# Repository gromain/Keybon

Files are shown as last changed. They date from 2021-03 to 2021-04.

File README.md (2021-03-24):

# Keybon - Adaptive Macro Keyboard

Keybon is a macro keyboard with configurable layouts and functions. Integrated into each of its nine tactile buttons is a 0.66” OLED screen. Depending on which app is active on the connected computer, Keybon switches to the suitable key layout thanks to its companion software.

This repository also contains a 12 buttons version called Keybon12. The corresponding files and code were designed by Romain Bazile. It's built upon the work of [CoretechR](https://github.com/CoretechR/Keybon/).

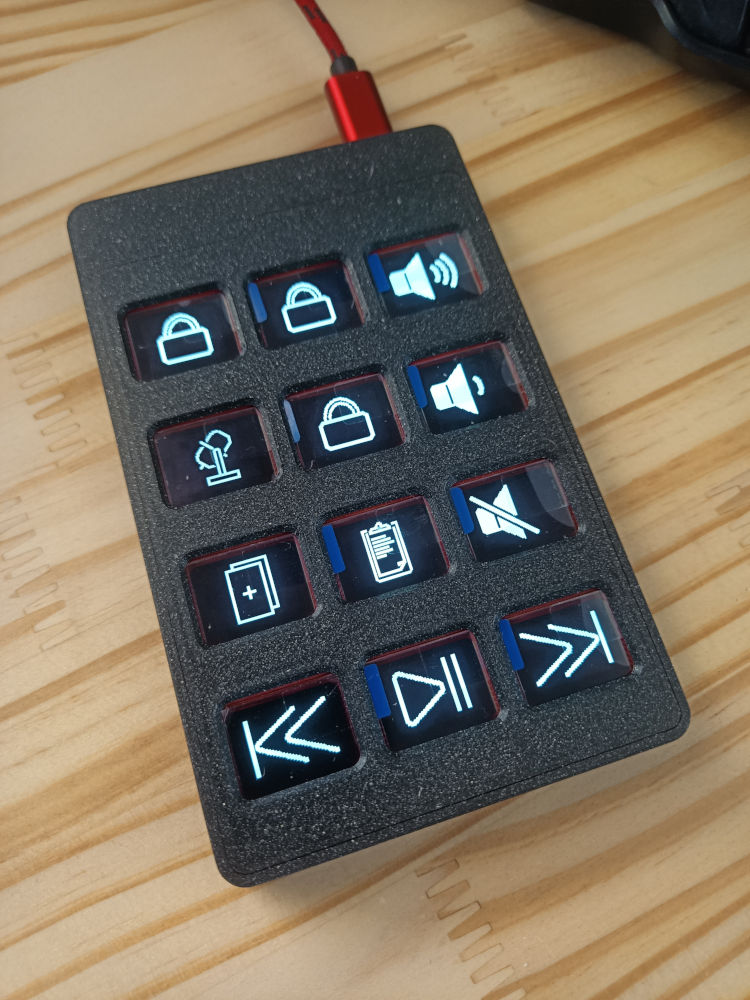
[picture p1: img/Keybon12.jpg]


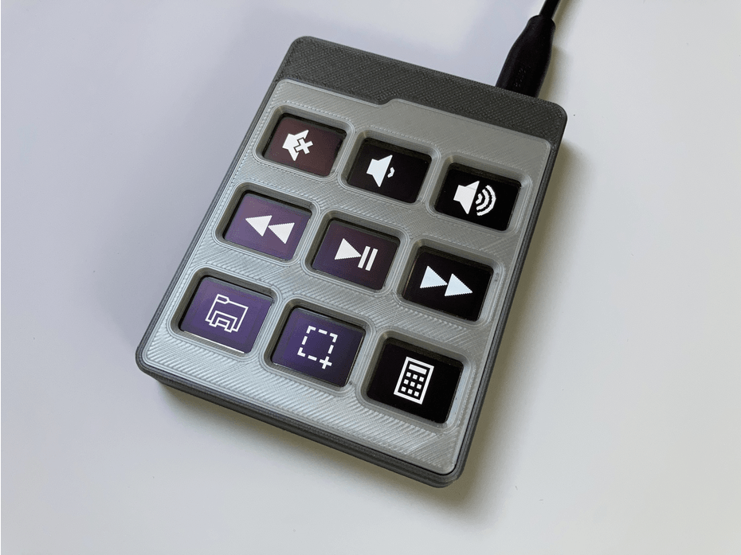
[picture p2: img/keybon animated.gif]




# Instructions

1.  Download the USB bootloader: https://github.com/rogerclarkmelbourne/STM32duino-bootloader

    Connect a USB-to-Serial adapter to the TX/RX pins of your board. Close the BOOT0 jumper before applying power.

    Locate the file to flash, in the folder `bootloader_only_binaries/generic_boot20_pc13.bin`.

    Flash the USB bootloader to the STM32 via the STM32 flasher:  https://www.st.com/en/development-tools/flasher-stm32.html

    You can also use the `stm32loader.py` script provided by `STM32duino-bootloader` team.

    Do not forget to remove the BOOT0 jumper once you're done.

2.  Install the required Arduino libraries listed in the `keybon12.ino` file

    Important: **Adafruit_GFX_Library version 1.7.5** must be installed (dependencies for newer versions are incompatible with the STM32)

    Add these lines to the file `Adafruit_SSD1306.c` (in `Arduino/libraries/Adafruit_SSD1306`)
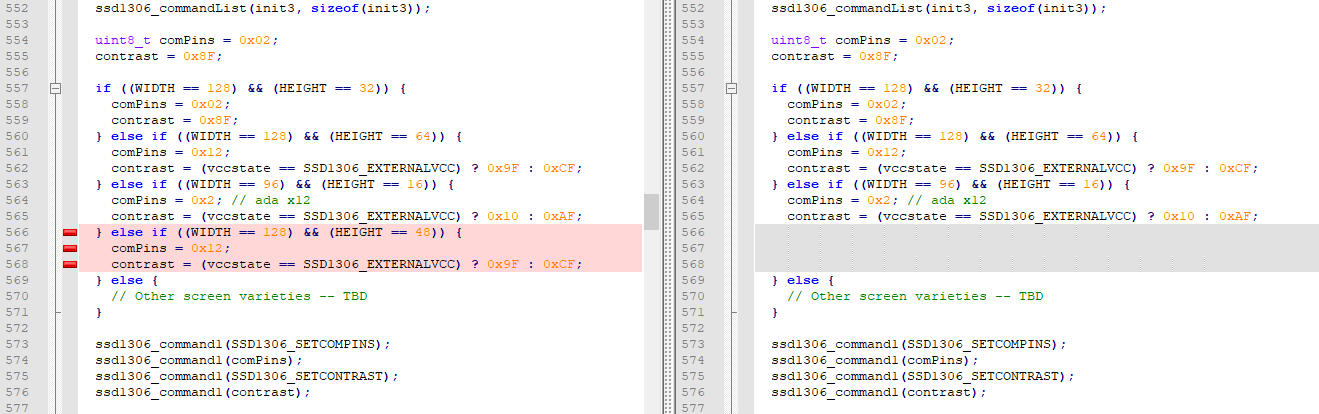
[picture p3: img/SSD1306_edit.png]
    
    ```C++
    } else if ((WIDTH == 128) && (HEIGHT == 48)) {
    comPins = 0x12;
	  contrast = (vccstate == SSD1306_EXTERNALVCC) ? 0x9F : 0xCF;
    ```

    They should be added around line 563, right after this:
    ```C++
    } else if ((WIDTH == 96) && (HEIGHT == 16)) {
    comPins = 0x2; // ada x12
    contrast = (vccstate == SSD1306_EXTERNALVCC) ? 0x10 : 0xAF;
    ```

3.  Install STM32 support for the Arduino IDE: https://github.com/rogerclarkmelbourne/Arduino_STM32

    Install the corresponding drivers: https://github.com/rogerclarkmelbourne/Arduino_STM32/tree/master/drivers

4.  Compile and upload the Arduino sketch:

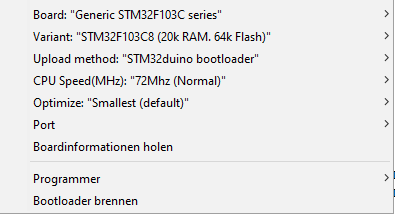
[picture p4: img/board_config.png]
    

    The first time you do this, you will need to short the BOOT1 jumper and then restart your Keybon (either by plugging it in, or by clicking on the reset button).

    If you are using Linux, you may need to add a udev rule to your system (or to use `sudo` with the last command executed by the Arduino IDE).

    If you need to create new icons for your display, you can use the tool at https://javl.github.io/image2cpp/ with png images, in black and white only and a resolution of 64*48 pixels.

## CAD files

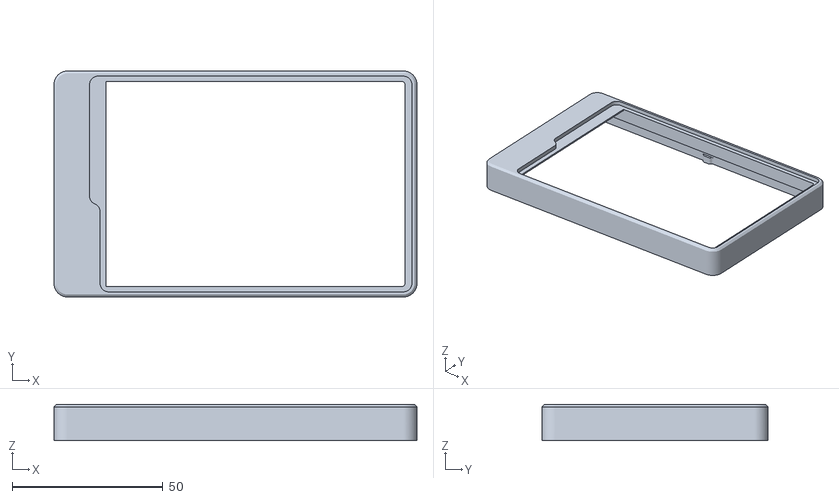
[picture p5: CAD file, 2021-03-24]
CAD Files/Shell Keybon12.stl
120.5 x 75.0 x 12.0

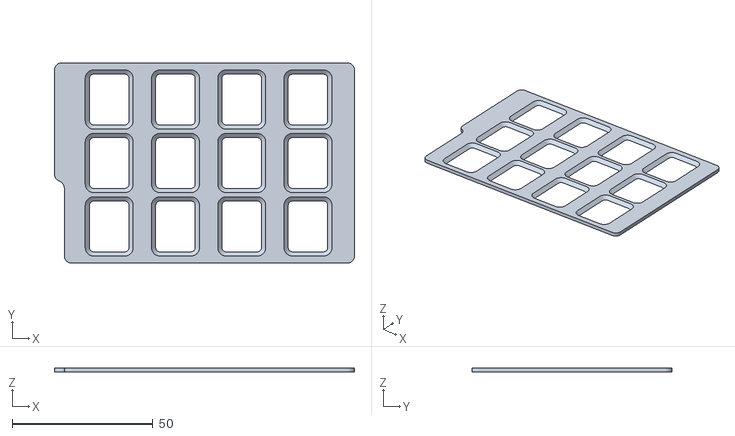
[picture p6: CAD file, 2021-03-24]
CAD Files/Cover Plate Keybon12.stl
106.4 x 71.0 x 1.50

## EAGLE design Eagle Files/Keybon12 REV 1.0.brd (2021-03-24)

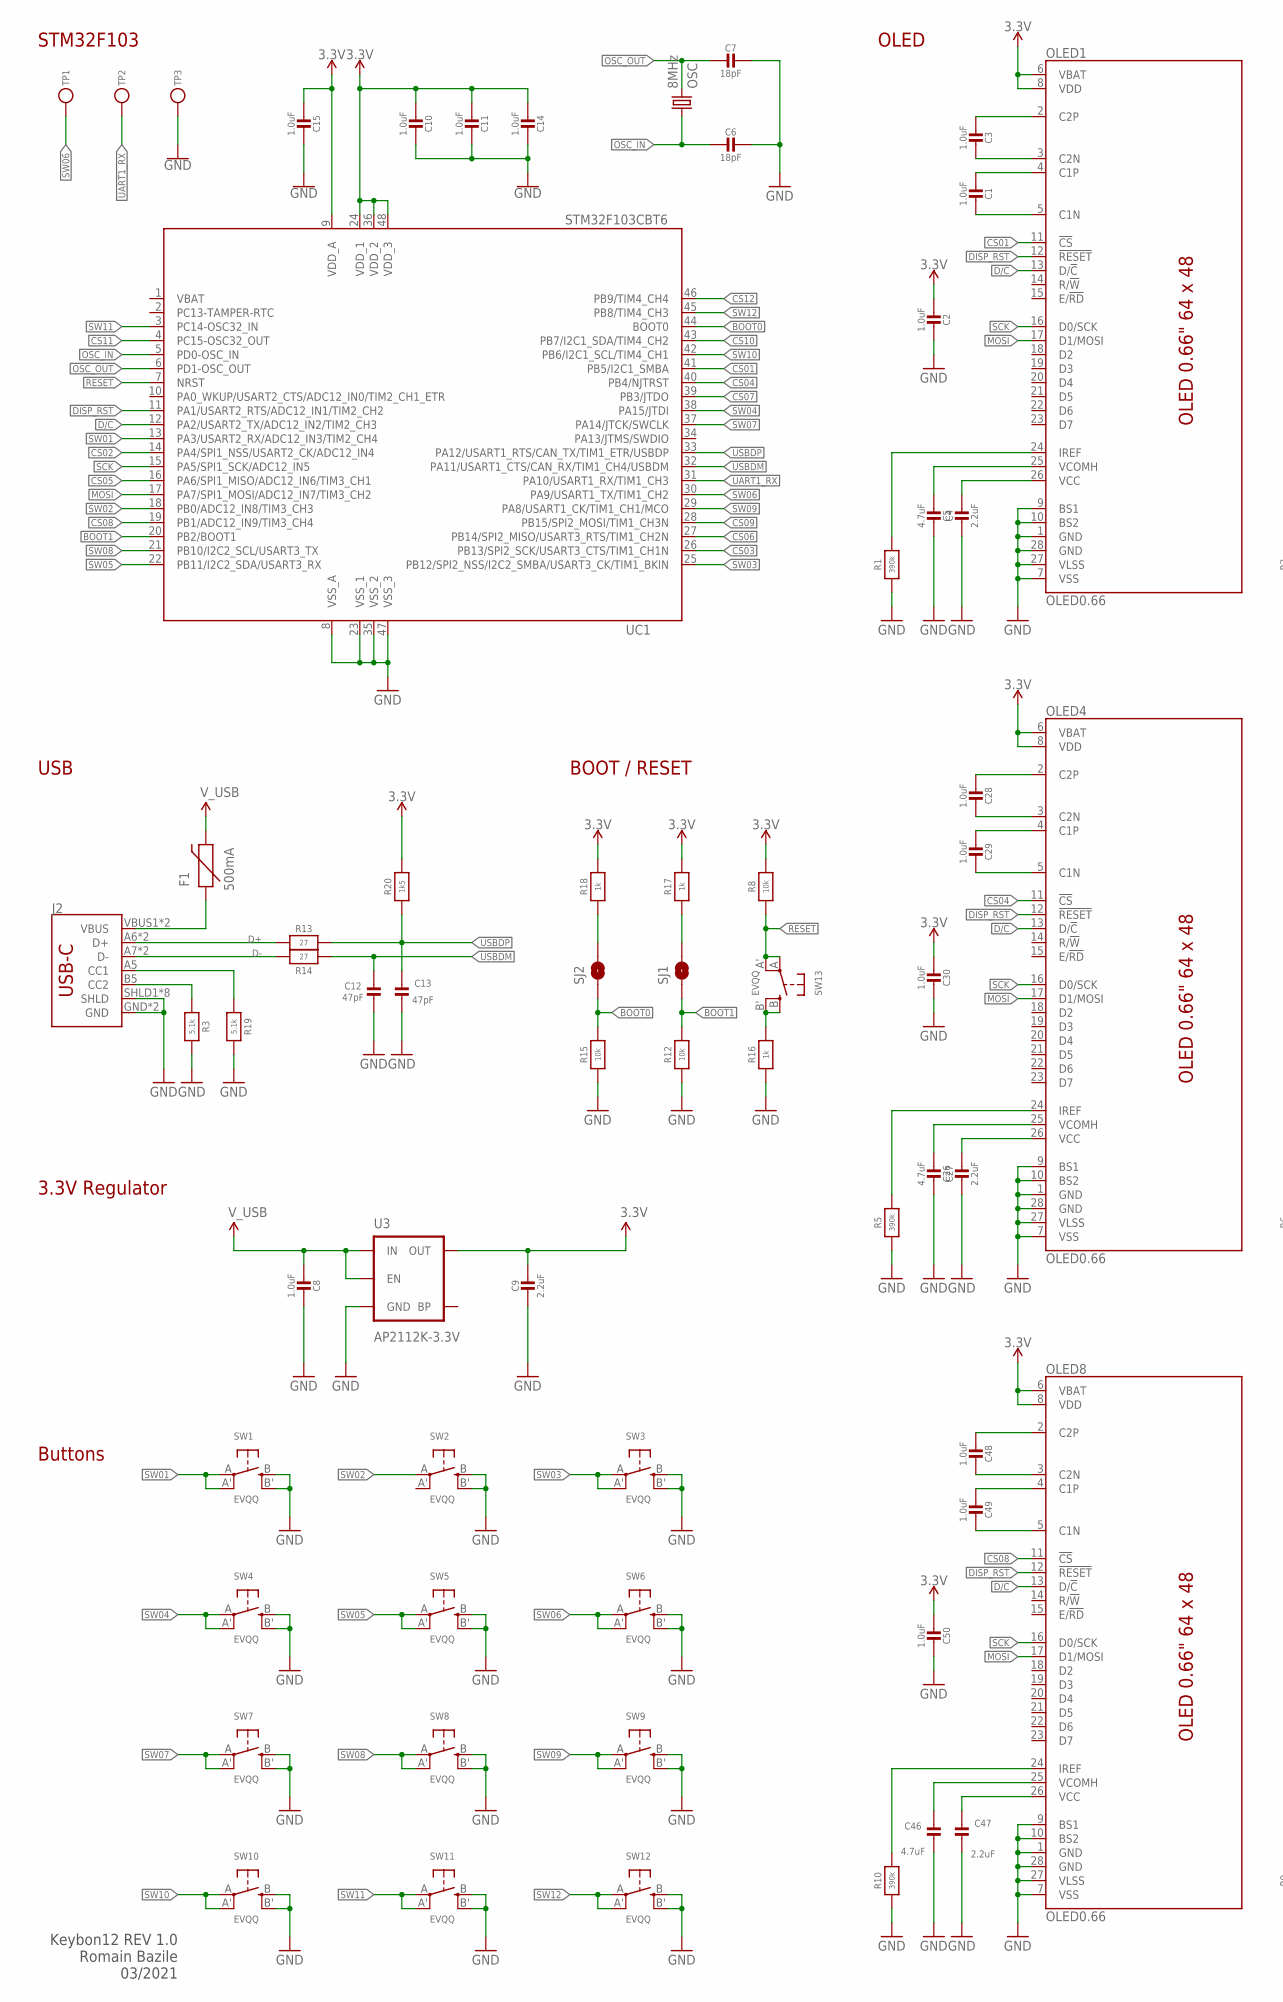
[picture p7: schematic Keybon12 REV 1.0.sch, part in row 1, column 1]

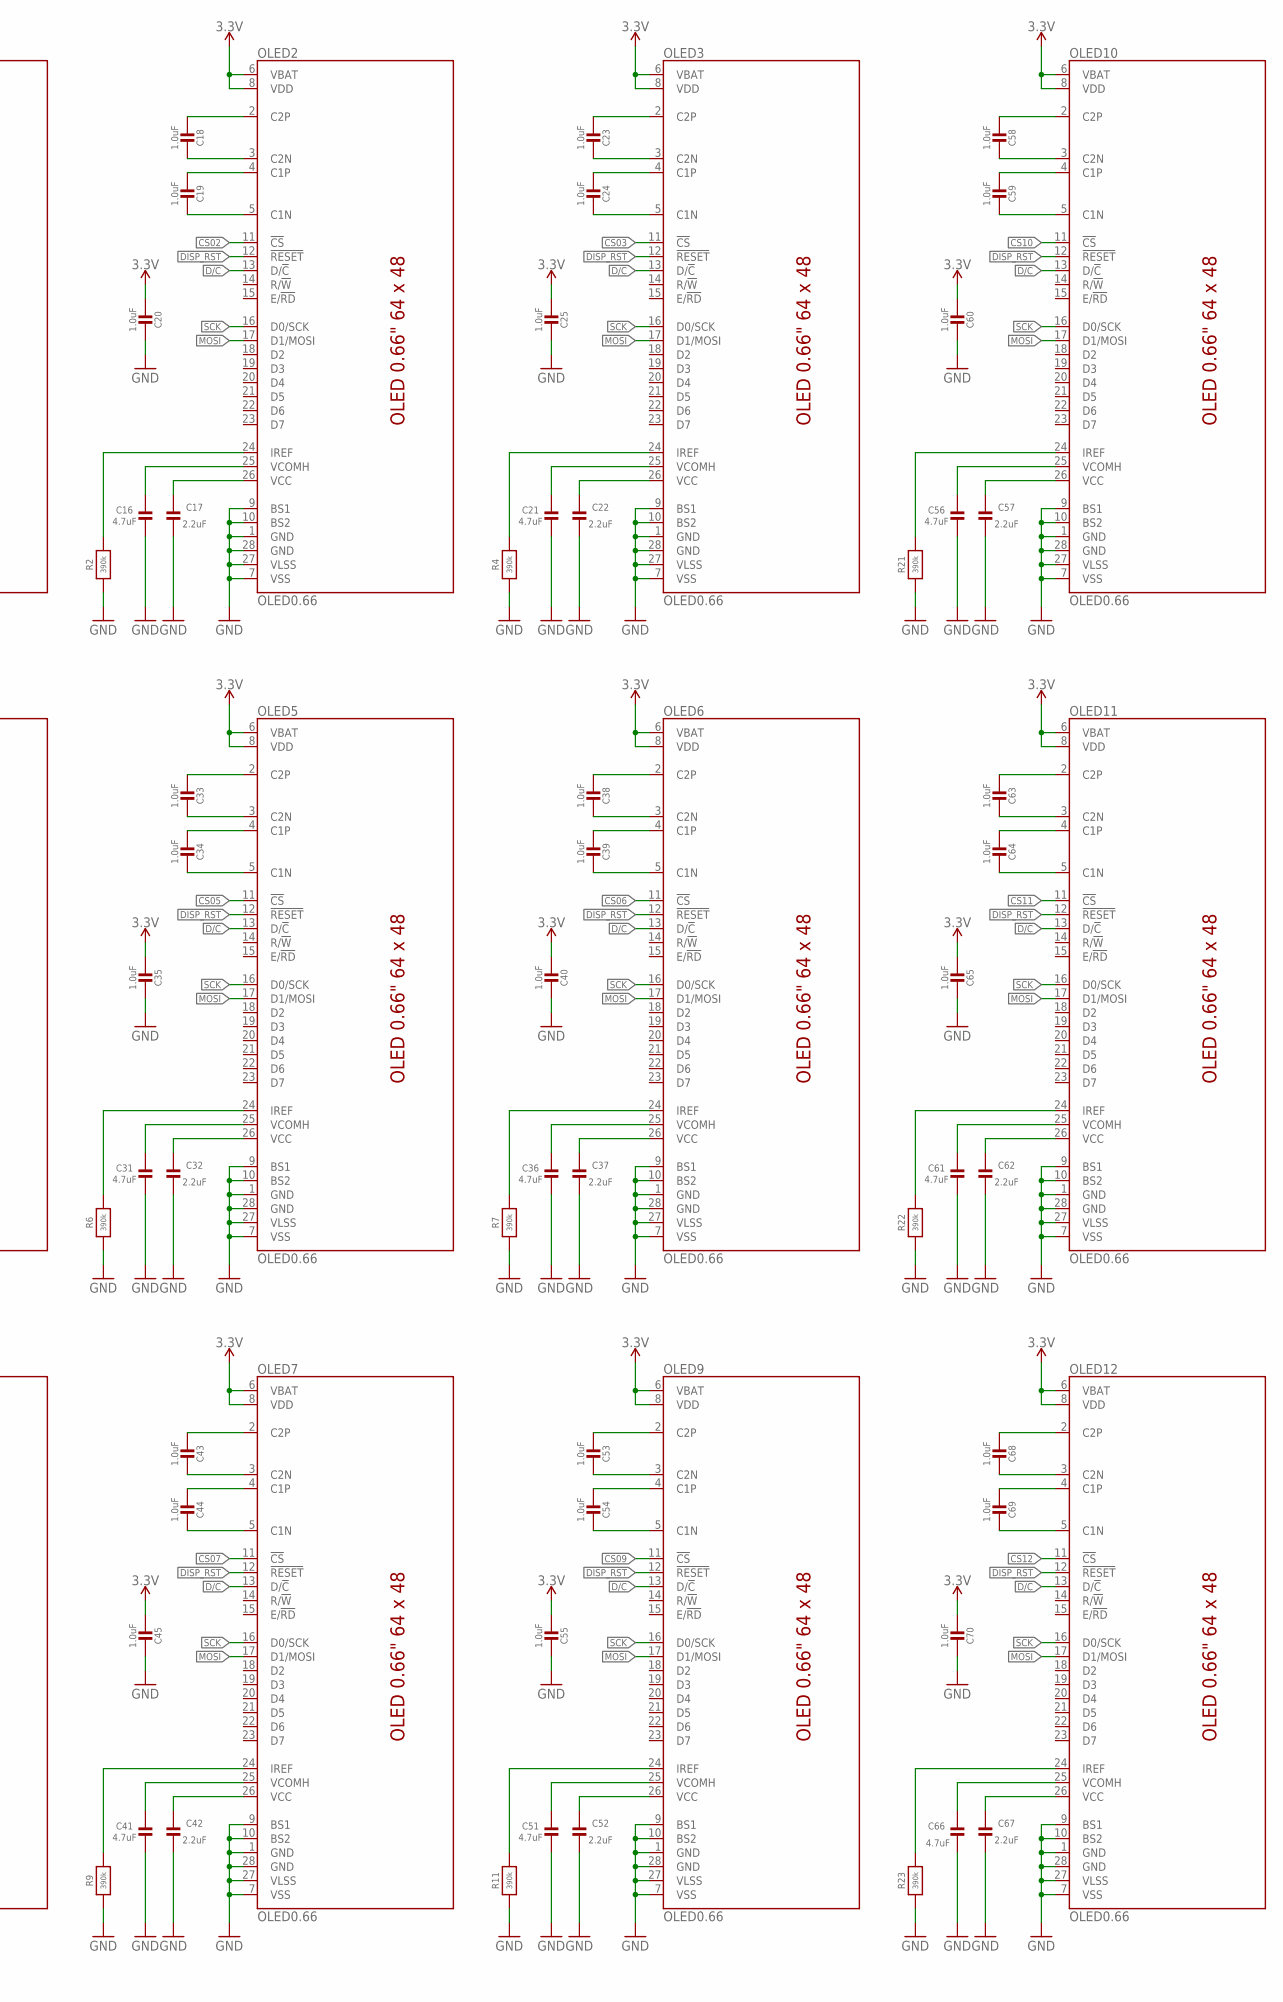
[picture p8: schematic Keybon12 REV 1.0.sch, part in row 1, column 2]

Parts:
C1, C2, C3, C8, C10, C11, C14, C15, C18, C19, C20, C23, C24, C25, C28, C29, C30, C33, C34, C35, C38, C39, C40, C43, C44, C45, C48, C49, C50, C53, C54, C55, C58, C59, C60, C63, C64, C65, C68, C69, C70: 1.0uF; _0805MP
C4, C9, C17, C22, C27, C32, C37, C42, C47, C52, C57, C62, C67: 2.2uF; _0805MP
C5, C16, C21, C26, C31, C36, C41, C46, C51, C56, C61, C66: 4.7uF; _0805MP
C6, C7: 18pF; _0805MP
C12, C13: 47pF; _0805MP
F1: 500mA; PTC-1206
J2: USB_C16PIN; USB-C-16P
OLED1, OLED2, OLED3, OLED4, OLED5, OLED6, OLED7, OLED8, OLED9, OLED10, OLED11, OLED12: OLED0.66; OLED-0.66-64X48
OSC: 8MHz; CRYSTAL-SMD-5X3
R1, R2, R4, R5, R6, R7, R9, R10, R11, R21, R22, R23: 390k; _0805MP
R3, R19: 5.1k; _0805MP
R8, R12, R15: 10k; _0805MP
R13, R14: 27; _0805MP
R16, R17, R18: 1k; _0805MP
R20: 1k5; _0805MP
SJ1, SJ2: JUMPER-PAD-2-NOYES_SILK; PAD-JUMPER-2-NO_YES_SILK
SW1, SW2, SW3, SW4, SW5, SW6, SW7, SW8, SW9, SW10, SW11, SW12, SW13: EVQQ; EVQ-Q2_SMALLER
TP1, TP2, TP3: TESTPOINTPAD2MM; TESTPOINT_PAD_2MM
U3: AP2112K-3.3V; SOT23-5
UC1: STM32F103CBT6; LQFP48

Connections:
3.3V: C2.1, C9.1, C10.1, C11.1, C14.1, C15.1, C20.1, C25.1, C30.1, C35.1, C40.1, C45.1, C50.1, C55.1, C60.1, C65.1, C70.1, OLED1.6 (VBAT), OLED1.8 (VDD), OLED2.6 (VBAT), OLED2.8 (VDD), OLED3.6 (VBAT), OLED3.8 (VDD), OLED4.6 (VBAT), OLED4.8 (VDD), OLED5.6 (VBAT), OLED5.8 (VDD), OLED6.6 (VBAT), OLED6.8 (VDD), OLED7.6 (VBAT), OLED7.8 (VDD), OLED8.6 (VBAT), OLED8.8 (VDD), OLED9.6 (VBAT), OLED9.8 (VDD), OLED10.6 (VBAT), OLED10.8 (VDD), OLED11.6 (VBAT), OLED11.8 (VDD), OLED12.6 (VBAT), OLED12.8 (VDD), R8.2, R17.2, R18.2, R20.2, U3.5 (OUT), UC1.9 (VDD_A), UC1.24 (VDD_1), UC1.36 (VDD_2), UC1.48 (VDD_3)
BOOT0: R15.2, SJ2.1, UC1.44 (BOOT0)
BOOT1: R12.2, SJ1.1, UC1.20 (PB2/BOOT1)
C1N: C1.2, OLED1.5 (C1N)
C1N1: C19.2, OLED2.5 (C1N)
C1N2: C24.2, OLED3.5 (C1N)
C1N3: C29.2, OLED4.5 (C1N)
C1N4: C34.2, OLED5.5 (C1N)
C1N5: C39.2, OLED6.5 (C1N)
C1N6: C44.2, OLED7.5 (C1N)
C1N7: C49.2, OLED8.5 (C1N)
C1N8: C54.2, OLED9.5 (C1N)
C1N9: C59.2, OLED10.5 (C1N)
C1N10: C64.2, OLED11.5 (C1N)
C1N11: C69.2, OLED12.5 (C1N)
C1P: C1.1, OLED1.4 (C1P)
C1P1: C19.1, OLED2.4 (C1P)
C1P2: C24.1, OLED3.4 (C1P)
C1P3: C29.1, OLED4.4 (C1P)
C1P4: C34.1, OLED5.4 (C1P)
C1P5: C39.1, OLED6.4 (C1P)
C1P6: C44.1, OLED7.4 (C1P)
C1P7: C49.1, OLED8.4 (C1P)
C1P8: C54.1, OLED9.4 (C1P)
C1P9: C59.1, OLED10.4 (C1P)
C1P10: C64.1, OLED11.4 (C1P)
C1P11: C69.1, OLED12.4 (C1P)
C2N: C3.2, OLED1.3 (C2N)
C2N1: C18.2, OLED2.3 (C2N)
C2N2: C23.2, OLED3.3 (C2N)
C2N3: C28.2, OLED4.3 (C2N)
C2N4: C33.2, OLED5.3 (C2N)
C2N5: C38.2, OLED6.3 (C2N)
C2N6: C43.2, OLED7.3 (C2N)
C2N7: C48.2, OLED8.3 (C2N)
C2N8: C53.2, OLED9.3 (C2N)
C2N9: C58.2, OLED10.3 (C2N)
C2N10: C63.2, OLED11.3 (C2N)
C2N11: C68.2, OLED12.3 (C2N)
C2P: C3.1, OLED1.2 (C2P)
C2P1: C18.1, OLED2.2 (C2P)
C2P2: C23.1, OLED3.2 (C2P)
C2P3: C28.1, OLED4.2 (C2P)
C2P4: C33.1, OLED5.2 (C2P)
C2P5: C38.1, OLED6.2 (C2P)
C2P6: C43.1, OLED7.2 (C2P)
C2P7: C48.1, OLED8.2 (C2P)
C2P8: C53.1, OLED9.2 (C2P)
C2P9: C58.1, OLED10.2 (C2P)
C2P10: C63.1, OLED11.2 (C2P)
C2P11: C68.1, OLED12.2 (C2P)
CS01: OLED1.11 (!CS!), UC1.41 (PB5/I2C1_SMBA)
CS02: OLED2.11 (!CS!), UC1.14 (PA4/SPI1_NSS/USART2_CK/ADC12_IN4)
CS03: OLED3.11 (!CS!), UC1.26 (PB13/SPI2_SCK/USART3_CTS/TIM1_CH1N)
CS04: OLED4.11 (!CS!), UC1.40 (PB4/NJTRST)
CS05: OLED5.11 (!CS!), UC1.16 (PA6/SPI1_MISO/ADC12_IN6/TIM3_CH1)
CS06: OLED6.11 (!CS!), UC1.27 (PB14/SPI2_MISO/USART3_RTS/TIM1_CH2N)
CS07: OLED7.11 (!CS!), UC1.39 (PB3/JTDO)
CS08: OLED8.11 (!CS!), UC1.19 (PB1/ADC12_IN9/TIM3_CH4)
CS09: OLED9.11 (!CS!), UC1.28 (PB15/SPI2_MOSI/TIM1_CH3N)
CS10: OLED10.11 (!CS!), UC1.43 (PB7/I2C1_SDA/TIM4_CH2)
CS11: OLED11.11 (!CS!), UC1.4 (PC15-OSC32_OUT)
CS12: OLED12.11 (!CS!), UC1.46 (PB9/TIM4_CH4)
D+: J2.A6 (D+), J2.B6 (D+), R13.1
D-: J2.A7 (D-), J2.B7 (D-), R14.1
D/C: OLED1.13 (D/!C!), OLED2.13 (D/!C!), OLED3.13 (D/!C!), OLED4.13 (D/!C!), OLED5.13 (D/!C!), OLED6.13 (D/!C!), OLED7.13 (D/!C!), OLED8.13 (D/!C!), OLED9.13 (D/!C!), OLED10.13 (D/!C!), OLED11.13 (D/!C!), OLED12.13 (D/!C!), UC1.12 (PA2/USART2_TX/ADC12_IN2/TIM2_CH3)
DISP_RST: OLED1.12 (!RESET!), OLED2.12 (!RESET!), OLED3.12 (!RESET!), OLED4.12 (!RESET!), OLED5.12 (!RESET!), OLED6.12 (!RESET!), OLED7.12 (!RESET!), OLED8.12 (!RESET!), OLED9.12 (!RESET!), OLED10.12 (!RESET!), OLED11.12 (!RESET!), OLED12.12 (!RESET!), UC1.11 (PA1/USART2_RTS/ADC12_IN1/TIM2_CH2)
GND: C2.2, C4.2, C5.2, C6.1, C7.1, C8.2, C9.2, C10.2, C11.2, C12.2, C13.2, C14.2, C15.2, C16.2, C17.2, C20.2, C21.2, C22.2, C25.2, C26.2, C27.2, C30.2, C31.2, C32.2, C35.2, C36.2, C37.2, C40.2, C41.2, C42.2, C45.2, C46.2, C47.2, C50.2, C51.2, C52.2, C55.2, C56.2, C57.2, C60.2, C61.2, C62.2, C65.2, C66.2, C67.2, C70.2, J2.GND, J2.GND2 (GND), J2.SHLD1 (SHLD), J2.SHLD2 (SHLD), J2.SHLD3 (SHLD), J2.SHLD4 (SHLD), J2.SHLD5 (SHLD), J2.SHLD6 (SHLD), J2.SHLD7 (SHLD), J2.SHLD8 (SHLD), OLED1.1 (GND), OLED1.7 (VSS), OLED1.9 (BS1), OLED1.10 (BS2), OLED1.27 (VLSS), OLED1.28 (GND), OLED2.1 (GND), OLED2.7 (VSS), OLED2.9 (BS1), OLED2.10 (BS2), OLED2.27 (VLSS), OLED2.28 (GND), OLED3.1 (GND), OLED3.7 (VSS), OLED3.9 (BS1), OLED3.10 (BS2), OLED3.27 (VLSS), OLED3.28 (GND), OLED4.1 (GND), OLED4.7 (VSS), OLED4.9 (BS1), OLED4.10 (BS2), OLED4.27 (VLSS), OLED4.28 (GND), OLED5.1 (GND), OLED5.7 (VSS), OLED5.9 (BS1), OLED5.10 (BS2), OLED5.27 (VLSS), OLED5.28 (GND), OLED6.1 (GND), OLED6.7 (VSS), OLED6.9 (BS1), OLED6.10 (BS2), OLED6.27 (VLSS), OLED6.28 (GND), OLED7.1 (GND), OLED7.7 (VSS), OLED7.9 (BS1), OLED7.10 (BS2), OLED7.27 (VLSS), OLED7.28 (GND), OLED8.1 (GND), OLED8.7 (VSS), OLED8.9 (BS1), OLED8.10 (BS2), OLED8.27 (VLSS), OLED8.28 (GND), OLED9.1 (GND), OLED9.7 (VSS), OLED9.9 (BS1), OLED9.10 (BS2), OLED9.27 (VLSS), OLED9.28 (GND), OLED10.1 (GND), OLED10.7 (VSS), OLED10.9 (BS1), OLED10.10 (BS2), OLED10.27 (VLSS), OLED10.28 (GND), OLED11.1 (GND), OLED11.7 (VSS), OLED11.9 (BS1), OLED11.10 (BS2), OLED11.27 (VLSS), OLED11.28 (GND), OLED12.1 (GND), OLED12.7 (VSS), OLED12.9 (BS1), OLED12.10 (BS2), OLED12.27 (VLSS), OLED12.28 (GND), R1.2, R2.2, R3.2, R4.2, R5.2, R6.2, R7.2, R9.2, R10.2, R11.2, R12.1, R15.1, R16.1, R19.2, R21.2, R22.2, R23.2, SW1.B (S), SW1.B' (S1), SW2.B (S), SW2.B' (S1), SW3.B (S), SW3.B' (S1), SW4.B (S), SW4.B' (S1), SW5.B (S), SW5.B' (S1), SW6.B (S), SW6.B' (S1), SW7.B (S), SW7.B' (S1), SW8.B (S), SW8.B' (S1), SW9.B (S), SW9.B' (S1), SW10.B (S), SW10.B' (S1), SW11.B (S), SW11.B' (S1), SW12.B (S), SW12.B' (S1), TP3.P$1, U3.2 (GND), UC1.8 (VSS_A), UC1.23 (VSS_1), UC1.35 (VSS_2), UC1.47 (VSS_3)
IREF: OLED1.24 (IREF), R1.1
IREF1: OLED2.24 (IREF), R2.1
IREF2: OLED3.24 (IREF), R4.1
IREF3: OLED4.24 (IREF), R5.1
IREF4: OLED5.24 (IREF), R6.1
IREF5: OLED6.24 (IREF), R7.1
IREF6: OLED7.24 (IREF), R9.1
IREF7: OLED8.24 (IREF), R10.1
IREF8: OLED9.24 (IREF), R11.1
IREF9: OLED10.24 (IREF), R21.1
IREF10: OLED11.24 (IREF), R22.1
IREF11: OLED12.24 (IREF), R23.1
MOSI: OLED1.17 (D1/MOSI), OLED2.17 (D1/MOSI), OLED3.17 (D1/MOSI), OLED4.17 (D1/MOSI), OLED5.17 (D1/MOSI), OLED6.17 (D1/MOSI), OLED7.17 (D1/MOSI), OLED8.17 (D1/MOSI), OLED9.17 (D1/MOSI), OLED10.17 (D1/MOSI), OLED11.17 (D1/MOSI), OLED12.17 (D1/MOSI), UC1.17 (PA7/SPI1_MOSI/ADC12_IN7/TIM3_CH2)
unnamed: R16.2, SW13.B (S), SW13.B' (S1)
unnamed: R18.1, SJ2.2
unnamed: R17.1, SJ1.2
unnamed: C4.1, OLED1.26 (VCC)
unnamed: C17.1, OLED2.26 (VCC)
unnamed: C22.1, OLED3.26 (VCC)
unnamed: C37.1, OLED6.26 (VCC)
unnamed: C32.1, OLED5.26 (VCC)
unnamed: J2.A5 (CC1), R19.1
unnamed: C27.1, OLED4.26 (VCC)
unnamed: J2.B5 (CC2), R3.1
unnamed: C47.1, OLED8.26 (VCC)
unnamed: C42.1, OLED7.26 (VCC)
unnamed: C52.1, OLED9.26 (VCC)
unnamed: C57.1, OLED10.26 (VCC)
unnamed: C62.1, OLED11.26 (VCC)
unnamed: C67.1, OLED12.26 (VCC)
OSC_IN: C6.2, OSC.1, UC1.5 (PD0-OSC_IN)
OSC_OUT: C7.2, OSC.3 (2), UC1.6 (PD1-OSC_OUT)
RESET: R8.1, SW13.A, SW13.A' (P1), UC1.7 (NRST)
SCK: OLED1.16 (D0/SCK), OLED2.16 (D0/SCK), OLED3.16 (D0/SCK), OLED4.16 (D0/SCK), OLED5.16 (D0/SCK), OLED6.16 (D0/SCK), OLED7.16 (D0/SCK), OLED8.16 (D0/SCK), OLED9.16 (D0/SCK), OLED10.16 (D0/SCK), OLED11.16 (D0/SCK), OLED12.16 (D0/SCK), UC1.15 (PA5/SPI1_SCK/ADC12_IN5)
SW01: SW1.A, SW1.A' (P1), UC1.13 (PA3/USART2_RX/ADC12_IN3/TIM2_CH4)
SW02: SW2.A, UC1.18 (PB0/ADC12_IN8/TIM3_CH3)
SW03: SW3.A, SW3.A' (P1), UC1.25 (PB12/SPI2_NSS/I2C2_SMBA/USART3_CK/TIM1_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)
SW04: SW4.A, SW4.A' (P1), UC1.38 (PA15/JTDI)
SW05: SW5.A, SW5.A' (P1), UC1.22 (PB11/I2C2_SDA/USART3_RX)
SW06: SW6.A, SW6.A' (P1), TP1.P$1, UC1.30 (PA9/USART1_TX/TIM1_CH2)
SW07: SW7.A, SW7.A' (P1), UC1.37 (PA14/JTCK/SWCLK)
SW08: SW8.A, SW8.A' (P1), UC1.21 (PB10/I2C2_SCL/USART3_TX)
SW09: SW9.A, SW9.A' (P1), UC1.29 (PA8/USART1_CK/TIM1_CH1/MCO)
SW10: SW10.A, SW10.A' (P1), UC1.42 (PB6/I2C1_SCL/TIM4_CH1)
SW11: SW11.A, SW11.A' (P1), UC1.3 (PC14-OSC32_IN)
SW12: SW12.A, SW12.A' (P1), UC1.45 (PB8/TIM4_CH3)
UART1_RX: TP2.P$1, UC1.31 (PA10/USART1_RX/TIM1_CH3)
USBDM: C12.1, R14.2, UC1.32 (PA11/USART1_CTS/CAN_RX/TIM1_CH4/USBDM)
USBDP: C13.1, R13.2, R20.1, UC1.33 (PA12/USART1_RTS/CAN_TX/TIM1_ETR/USBDP)
VBAT: UC1.1 (VBAT)
VCOMH: C5.1, OLED1.25 (VCOMH)
VCOMH1: C16.1, OLED2.25 (VCOMH)
VCOMH2: C21.1, OLED3.25 (VCOMH)
VCOMH3: C26.1, OLED4.25 (VCOMH)
VCOMH4: C31.1, OLED5.25 (VCOMH)
VCOMH5: C36.1, OLED6.25 (VCOMH)
VCOMH6: C41.1, OLED7.25 (VCOMH)
VCOMH7: C46.1, OLED8.25 (VCOMH)
VCOMH8: C51.1, OLED9.25 (VCOMH)
VCOMH9: C56.1, OLED10.25 (VCOMH)
VCOMH10: C61.1, OLED11.25 (VCOMH)
VCOMH11: C66.1, OLED12.25 (VCOMH)
VUSB-RAW: F1.1, J2.VBUS1 (VBUS), J2.VBUS2 (VBUS)
V_USB: C8.1, F1.2, U3.1 (IN), U3.3 (EN)

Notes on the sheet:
Buttons
OLED
STM32F103
USB
BOOT / RESET
3.3V Regulator
Keybon12 REV 1.0 Romain Bazile 03/2021

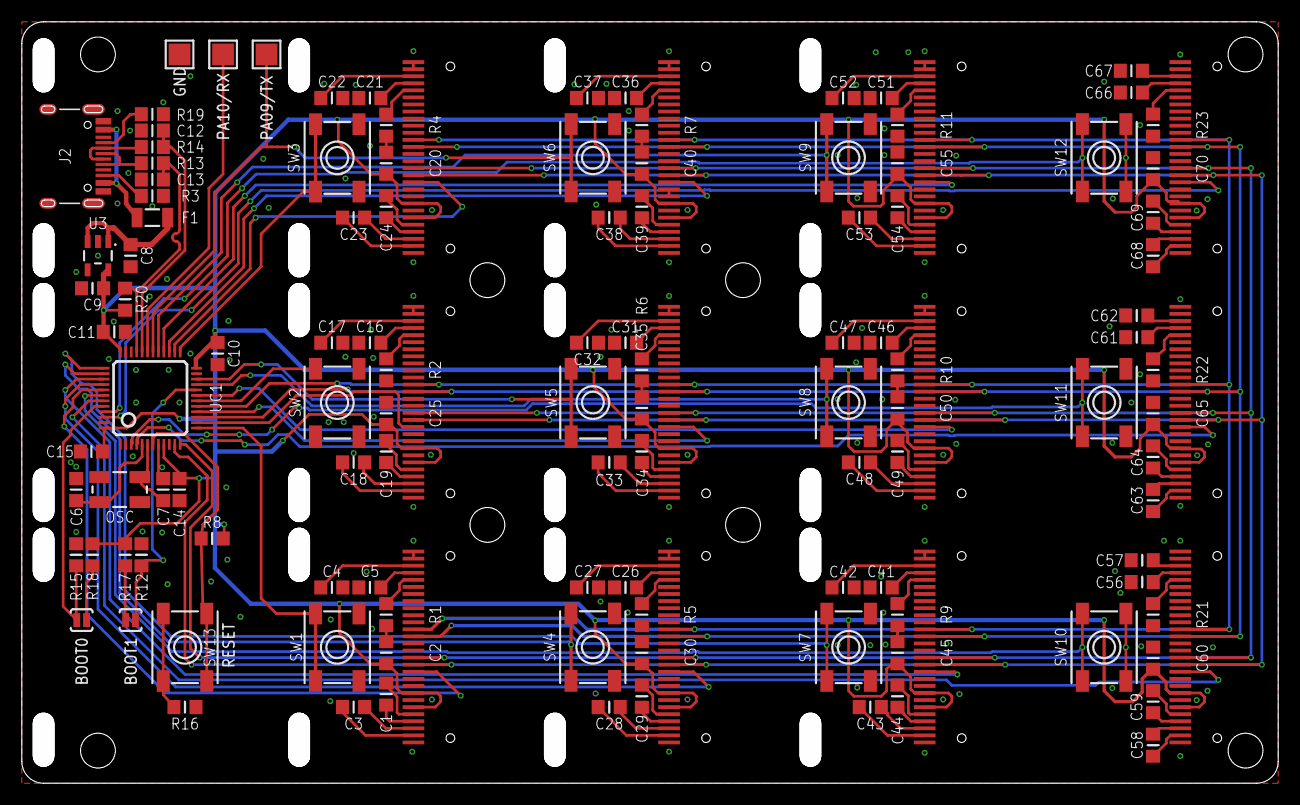
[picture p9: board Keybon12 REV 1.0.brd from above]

Board: 2 copper layers, 115.5 x 70.0 mm, 128 parts (0 on the bottom side), 131 nets.

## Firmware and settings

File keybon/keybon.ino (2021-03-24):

#include <USBComposite.h>
#include <SPI.h>
#include <Wire.h>
#include <Adafruit_GFX.h> // v1.7.5 needed
#include <Adafruit_SSD1306.h>
#include <JC_Button.h> // https://github.com/JChristensen/JC_Button
#include "bmp.h"

USBHID HID;
HIDKeyboard Keyboard(HID);
HIDConsumer Consumer(HID);
USBCompositeSerial CompositeSerial;


#define PRODUCT_ID 0x29

#define SW01 PA3
#define SW02 PB0
#define SW03 PB12
#define SW04 PA15
#define SW05 PB11
#define SW06 PA9
#define SW07 PA14
#define SW08 PB10
#define SW09 PA8

#define OLED_MOSI  PA7
#define OLED_CLK   PA5
#define OLED_DC    PA2
#define OLED_CS01    PB5
#define OLED_CS02    PA4
#define OLED_CS03    PB13
#define OLED_CS04    PB4
#define OLED_CS05    PA6
#define OLED_CS06    PB14
#define OLED_CS07    PB3
#define OLED_CS08    PB1
#define OLED_CS09    PB15
#define OLED_RESET PA1

Adafruit_SSD1306 OLED01(128, 48, OLED_MOSI, OLED_CLK, OLED_DC, OLED_RESET, OLED_CS01);
Adafruit_SSD1306 OLED02(128, 48, OLED_MOSI, OLED_CLK, OLED_DC, OLED_RESET, OLED_CS02);
Adafruit_SSD1306 OLED03(128, 48, OLED_MOSI, OLED_CLK, OLED_DC, OLED_RESET, OLED_CS03);
Adafruit_SSD1306 OLED04(128, 48, OLED_MOSI, OLED_CLK, OLED_DC, OLED_RESET, OLED_CS04);
Adafruit_SSD1306 OLED05(128, 48, OLED_MOSI, OLED_CLK, OLED_DC, OLED_RESET, OLED_CS05);
Adafruit_SSD1306 OLED06(128, 48, OLED_MOSI, OLED_CLK, OLED_DC, OLED_RESET, OLED_CS06);
Adafruit_SSD1306 OLED07(128, 48, OLED_MOSI, OLED_CLK, OLED_DC, OLED_RESET, OLED_CS07);
Adafruit_SSD1306 OLED08(128, 48, OLED_MOSI, OLED_CLK, OLED_DC, OLED_RESET, OLED_CS08);
Adafruit_SSD1306 OLED09(128, 48, OLED_MOSI, OLED_CLK, OLED_DC, OLED_RESET, OLED_CS09);

Button button01(SW01, 5, true, true); //pin, debounce, pullup, invert
Button button02(SW02, 5, true, true); //pin, debounce, pullup, invert
Button button03(SW03, 5, true, true); //pin, debounce, pullup, invert
Button button04(SW04, 5, true, true); //pin, debounce, pullup, invert
Button button05(SW05, 5, true, true); //pin, debounce, pullup, invert
Button button06(SW06, 5, true, true); //pin, debounce, pullup, invert
Button button07(SW07, 5, true, true); //pin, debounce, pullup, invert
Button button08(SW08, 5, true, true); //pin, debounce, pullup, invert
Button button09(SW09, 5, true, true); //pin, debounce, pullup, invert

unsigned int cursor = 0;

boolean defaultLayoutActive = true;


void setup() {
  pinMode(SW01, INPUT_PULLUP);
  pinMode(SW02, INPUT_PULLUP);
  pinMode(SW03, INPUT_PULLUP);
  pinMode(SW04, INPUT_PULLUP);
  pinMode(SW05, INPUT_PULLUP);
  pinMode(SW06, INPUT_PULLUP);
  pinMode(SW07, INPUT_PULLUP);
  pinMode(SW08, INPUT_PULLUP);
  pinMode(SW09, INPUT_PULLUP);
  
  button01.begin();
  button02.begin();
  button03.begin();
  button04.begin();
  button05.begin();
  button06.begin();
  button07.begin();
  button08.begin();
  button09.begin();
  
  USBComposite.setProductId(PRODUCT_ID);
  HID.registerComponent();
  CompositeSerial.registerComponent();
  USBComposite.begin();

  OLED01.begin(SSD1306_SWITCHCAPVCC, 0, true, true); // OLEDs share same reset line, o
  OLED01.setRotation(0);
  OLED02.begin(SSD1306_SWITCHCAPVCC, 0, false, true);
  OLED02.setRotation(0);
  OLED03.begin(SSD1306_SWITCHCAPVCC, 0, false, true);
  OLED03.setRotation(0);
  OLED04.begin(SSD1306_SWITCHCAPVCC, 0, false, true);
  OLED04.setRotation(0);
  OLED05.begin(SSD1306_SWITCHCAPVCC, 0, false, true);
  OLED05.setRotation(0);
  OLED06.begin(SSD1306_SWITCHCAPVCC, 0, false, true);
  OLED06.setRotation(0);
  OLED07.begin(SSD1306_SWITCHCAPVCC, 0, false, true);
  OLED07.setRotation(0);
  OLED08.begin(SSD1306_SWITCHCAPVCC, 0, false, true);
  OLED08.setRotation(0);
  OLED09.begin(SSD1306_SWITCHCAPVCC, 0, false, true);
  OLED09.setRotation(0);

  displayContrast(LOW);
  
  OLED01.clearDisplay();   // clears the screen and buffer
  OLED02.clearDisplay();
  OLED03.clearDisplay();
  OLED04.clearDisplay();
  OLED05.clearDisplay();
  OLED06.clearDisplay();
  OLED07.clearDisplay();
  OLED08.clearDisplay();
  OLED09.clearDisplay();
  
  //delay(500);
  CompositeSerial.setTimeout(200);

  OLED01.drawBitmap(32, 0, bmp_mute, 64, 48, WHITE);
  OLED02.drawBitmap(32, 0, bmp_volume_down, 64, 48, WHITE);
  OLED03.drawBitmap(32, 0, bmp_volume_up, 64, 48, WHITE);
  OLED04.drawBitmap(32, 0, bmp_backward, 64, 48, WHITE);
  OLED05.drawBitmap(32, 0, bmp_play, 64, 48, WHITE);
  OLED06.drawBitmap(32, 0, bmp_forward, 64, 48, WHITE);
  OLED07.drawBitmap(32, 0, bmp_explorer, 64, 48, WHITE);
  OLED08.drawBitmap(32, 0, bmp_snapshot, 64, 48, WHITE);
  OLED09.drawBitmap(32, 0, bmp_calc, 64, 48, WHITE);
}

void loop() {

  if(button01.wasPressed() or button01.pressedFor(300)){
    if(defaultLayoutActive){
      Consumer.press(HIDConsumer::MUTE);
      Consumer.release();
    }
    else CompositeSerial.print("1");
  }
  if(button02.wasPressed() or button02.pressedFor(300)){
    if(defaultLayoutActive){
      Consumer.press(HIDConsumer::VOLUME_DOWN);
      Consumer.release();
    }
    else CompositeSerial.print("2");
  }
  if(button03.wasPressed() or button03.pressedFor(300)){
    if(defaultLayoutActive){
      Consumer.press(HIDConsumer::VOLUME_UP);
      Consumer.release();
    }
    else CompositeSerial.print("3");
  }
  if(button04.wasPressed() or button04.pressedFor(300)){
    if(defaultLayoutActive){
      Consumer.press(182);
      Consumer.release();
    }
    else CompositeSerial.print("4");
  }
  if(button05.wasPressed() or button05.pressedFor(300)){
    if(defaultLayoutActive){
      Consumer.press(HIDConsumer::PLAY_OR_PAUSE);
      Consumer.release();
    }
    else CompositeSerial.print("5");
  }
  if(button06.wasPressed() or button06.pressedFor(300)){
    if(defaultLayoutActive){
      Consumer.press(181);
      Consumer.release();
    }
    else CompositeSerial.print("6");
  }
  if(button07.wasPressed() or button07.pressedFor(300)){
    if(defaultLayoutActive){
      Keyboard.press(KEY_LEFT_GUI);
      Keyboard.press('e');
      Keyboard.release('e');
      Keyboard.release(KEY_LEFT_GUI);
    }
    else CompositeSerial.print("7");
  }
  if(button08.wasPressed() or button08.pressedFor(300)){
    if(defaultLayoutActive){
      Keyboard.press(KEY_LEFT_GUI);
      Keyboard.press(KEY_LEFT_SHIFT);
      Keyboard.press('s');
      Keyboard.release('s');
      Keyboard.release(KEY_LEFT_SHIFT);
      Keyboard.release(KEY_LEFT_GUI);
    }
    else CompositeSerial.print("8");
  }
  if(button09.wasPressed() or button09.pressedFor(300)){
    if(defaultLayoutActive){
      Keyboard.press(KEY_LEFT_GUI);
      Keyboard.press('r');
      Keyboard.release('r');
      Keyboard.release(KEY_LEFT_GUI);
      Keyboard.print("calc");
      Keyboard.press('\n');
      Keyboard.release('\n');
    }
    else CompositeSerial.print("9");
  }

  
  while (CompositeSerial.available() > 0){
    byte command = CompositeSerial.read();
    if(command >= '0' && command <= '8'){
      defaultLayoutActive = false;
      CompositeSerial.readBytes(bmp_swap,384);
      if(command == '0'){
        OLED01.clearDisplay();
        OLED01.drawBitmap(32, 0, bmp_swap, 64, 48, WHITE);
      }
      if(command == '1'){
        OLED02.clearDisplay();
        OLED02.drawBitmap(32, 0, bmp_swap, 64, 48, WHITE);
      }
      if(command == '2'){
        OLED03.clearDisplay();
        OLED03.drawBitmap(32, 0, bmp_swap, 64, 48, WHITE);
      }
      if(command == '3'){
        OLED04.clearDisplay();
        OLED04.drawBitmap(32, 0, bmp_swap, 64, 48, WHITE);
      }
      if(command == '4'){
        OLED05.clearDisplay();
        OLED05.drawBitmap(32, 0, bmp_swap, 64, 48, WHITE);
      }
      if(command == '5'){
        OLED06.clearDisplay();
        OLED06.drawBitmap(32, 0, bmp_swap, 64, 48, WHITE);
      }
      if(command == '6'){
        OLED07.clearDisplay();
        OLED07.drawBitmap(32, 0, bmp_swap, 64, 48, WHITE);
      }
      if(command == '7'){
        OLED08.clearDisplay();
        OLED08.drawBitmap(32, 0, bmp_swap, 64, 48, WHITE);
      }
      if(command == '8'){
        OLED09.clearDisplay();
        OLED09.drawBitmap(32, 0, bmp_swap, 64, 48, WHITE);
      }
    }
    else if(command == 'D'){ //fallback to internal Layout
      defaultLayoutActive = true;
      OLED01.clearDisplay();   // clears the screen and buffer
      OLED02.clearDisplay();
      OLED03.clearDisplay();
      OLED04.clearDisplay();
      OLED05.clearDisplay();
      OLED06.clearDisplay();
      OLED07.clearDisplay();
      OLED08.clearDisplay();
      OLED09.clearDisplay();
      OLED01.drawBitmap(32, 0, bmp_mute, 64, 48, WHITE);
      OLED02.drawBitmap(32, 0, bmp_volume_down, 64, 48, WHITE);
      OLED03.drawBitmap(32, 0, bmp_volume_up, 64, 48, WHITE);
      OLED04.drawBitmap(32, 0, bmp_backward, 64, 48, WHITE);
      OLED05.drawBitmap(32, 0, bmp_play, 64, 48, WHITE);
      OLED06.drawBitmap(32, 0, bmp_forward, 64, 48, WHITE);
      OLED07.drawBitmap(32, 0, bmp_explorer, 64, 48, WHITE);
      OLED08.drawBitmap(32, 0, bmp_snapshot, 64, 48, WHITE);
      OLED09.drawBitmap(32, 0, bmp_calc, 64, 48, WHITE);
    }
    else if(command == 'A'){ //Answer to call
      CompositeSerial.print("a");
    }
    else if(command == 'B'){ //high brightness
      displayContrast(HIGH);
    }
    else if(command == 'b'){ //low brightness
      displayContrast(LOW);
    }
  }
  
  //OLED09.setCursor(32, 10);
  //OLED09.setTextColor(WHITE);
  //OLED09.setTextSize(1);
  //OLED09.print(cursor);

  OLED01.display();
  OLED02.display();
  OLED03.display();
  OLED04.display();
  OLED05.display();
  OLED06.display();
  OLED07.display();
  OLED08.display();
  OLED09.display();

  button01.read();
  button02.read();
  button03.read();
  button04.read();
  button05.read();
  button06.read();
  button07.read();
  button08.read();
  button09.read();

}

void displayContrast(boolean contrast){
  byte contrastSetting = 0x35;
  if(contrast == HIGH) contrastSetting = 0x7F;
  
  OLED01.ssd1306_command(SSD1306_SETCONTRAST);
  OLED01.ssd1306_command(contrastSetting);
  OLED02.ssd1306_command(SSD1306_SETCONTRAST);
  OLED02.ssd1306_command(contrastSetting);
  OLED03.ssd1306_command(SSD1306_SETCONTRAST);
  OLED03.ssd1306_command(contrastSetting);
  OLED04.ssd1306_command(SSD1306_SETCONTRAST);
  OLED04.ssd1306_command(contrastSetting);
  OLED05.ssd1306_command(SSD1306_SETCONTRAST);
  OLED05.ssd1306_command(contrastSetting);
  OLED06.ssd1306_command(SSD1306_SETCONTRAST);
  OLED06.ssd1306_command(contrastSetting);
  OLED07.ssd1306_command(SSD1306_SETCONTRAST);
  OLED07.ssd1306_command(contrastSetting);
  OLED08.ssd1306_command(SSD1306_SETCONTRAST);
  OLED08.ssd1306_command(contrastSetting);
  OLED09.ssd1306_command(SSD1306_SETCONTRAST);
  OLED09.ssd1306_command(contrastSetting);
}

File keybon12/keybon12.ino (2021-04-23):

#include <USBComposite.h>
#include <SPI.h>
#include <Wire.h>
#include <Adafruit_GFX.h> //v1.7.5
#include <Adafruit_SSD1306.h>
#include <JC_Button.h> // https://github.com/JChristensen/JC_Button v2.1.2
#include "bmp.h"
#include "hardware.h"

USBHID HID;
HIDKeyboard Keyboard(HID);
HIDConsumer Consumer(HID);
USBCompositeSerial CompositeSerial;

unsigned int cursor = 0;

void fVolumeUp(void);
void fVolumeDown(void);
void fMute(void);
void fMuteMic(void);
void fLock(void);
void fCut(void);
void fPaste(void);
void fForward(void);
void fBackward(void);
void fPlay(void);
void fTerm(void);
void fCalc(void);

boolean defaultLayoutActive = true;

typedef enum eKeyName{
	key01 = 1,
	key02 = 2,
	key03 = 3,
	key04 = 4,
	key05 = 5,
	key06 = 6,
	key07 = 7,
	key08 = 8,
	key09 = 9,
	key10 = 10,
	key11 = 11,
	key12 = 12
} eKeyName;

typedef enum eFunction{
	MUTE,
	PLAY,
	FORWARD,
	BACKWARD,
	CUT,
	PASTE,
	VOL_UP,
	VOL_DOWN,
	MIC_MUTE,
	LOCK,
	TERM,
	CALC
} eFunction;

typedef struct tFunction {
	eFunction Function;
  void (*Call) (void);
  const unsigned char *Icon ;
} tFunction;

tFunction functionsArray[] = {
  {MUTE,      fMute,        bmp_mute},
  {PLAY,      fPlay,        bmp_play},
  {FORWARD,   fForward,     bmp_forward},
  {BACKWARD,  fBackward,    bmp_backward},
  {CUT,       fCut,         bmp_cut},
  {PASTE,     fPaste,       bmp_paste},
  {VOL_UP,    fVolumeUp,    bmp_volume_up},
  {VOL_DOWN,  fVolumeDown,  bmp_volume_down},
  {MIC_MUTE,  fMuteMic,     bmp_microphone},
  {LOCK,      fLock,        bmp_lock},
  {TERM,      fTerm,        bmp_term},
  {CALC,      fCalc,        bmp_calc2}
};

typedef struct tkey {
	eKeyName Name;
  Button* Key;
  Adafruit_SSD1306* OLED;
	eFunction Function;
} tkey;

/* KeyMap of the Keybon12 device

  Key01 | Key02 | Key03
  Key04 | Key05 | Key06
  Key01 | Key02 | Key09
  Key10 | Key11 | Key12

*/
tkey keyArray[] = {
  {key01, &button01, &OLED01, LOCK},      {key02, &button02, &OLED02, CALC}, {key03, &button03, &OLED03, MIC_MUTE},
	{key04, &button04, &OLED04, CUT}, 			{key05, &button05, &OLED05, PASTE},     {key06, &button06, &OLED06, TERM},
	{key07, &button07, &OLED07, VOL_DOWN},	{key08, &button08, &OLED08, MUTE},	   {key09, &button09, &OLED09, VOL_UP},
	{key10, &button10, &OLED10, BACKWARD},	{key11, &button11, &OLED11, PLAY},	   {key12, &button12, &OLED12, FORWARD}
};

void setup() {
  pinMode(SW01, INPUT_PULLUP);
  pinMode(SW02, INPUT_PULLUP);
  pinMode(SW03, INPUT_PULLUP);
  pinMode(SW04, INPUT_PULLUP);
  pinMode(SW05, INPUT_PULLUP);
  pinMode(SW06, INPUT_PULLUP);
  pinMode(SW07, INPUT_PULLUP);
  pinMode(SW08, INPUT_PULLUP);
  pinMode(SW09, INPUT_PULLUP);
  pinMode(SW10, INPUT_PULLUP);
  pinMode(SW11, INPUT_PULLUP);
  pinMode(SW12, INPUT_PULLUP);

  for (uint8_t i = 0; i < 12; i++) {
    keyArray[i].Key->begin();
  };

  USBComposite.setProductId(PRODUCT_ID);
  HID.registerComponent();
  CompositeSerial.registerComponent();
  USBComposite.begin();

  OLED01.begin(SSD1306_SWITCHCAPVCC, 0, true, true); // OLEDs share same reset line, o
  OLED01.setRotation(0);

  for (uint8_t i = 1; i < 12; i++) {
    keyArray[i].OLED->begin(SSD1306_SWITCHCAPVCC, 0, false, true);
    keyArray[i].OLED->setRotation(0);
  };

  displayContrast(LOW);

  //delay(500);
  CompositeSerial.setTimeout(200);

  for (uint8_t i = 0; i < 12; i++) {
    keyArray[i].OLED->clearDisplay();   // clears the screen and buffer
    keyArray[i].OLED->drawBitmap(32, 0, functionsArray[keyArray[i].Function].Icon, 64, 48, WHITE);
  };
}


void loop() {
  for (uint8_t i = 0; i < 12; i++) {
    if (keyArray[i].Key->wasPressed() or keyArray[i].Key->pressedFor(300)) {
      if (defaultLayoutActive) {
        functionsArray[keyArray[i].Function].Call();
      }
      else CompositeSerial.print(char(i+0x30)); // 0x30 is the ASCII table offset for character '0'
    }
  };

  while (CompositeSerial.available() > 0) {
    byte command = CompositeSerial.read();
		switch (command) {
			case '0':		// Key1
			case '1':		// Key2, etc...
			case '2':		// they all fall through to the same handling code
			case '3':
			case '4':
			case '5':
			case '6':
			case '7':
			case '8':
			case '9':
			case ':':
			case ';':
				defaultLayoutActive = false;
				CompositeSerial.readBytes(bmp_swap, 384);
				keyArray[command-0x30].OLED->clearDisplay();
				keyArray[command-0x30].OLED->drawBitmap(32, 0, bmp_swap, 64, 48, WHITE);
				break;
			case 'A': //Answer to call
	      CompositeSerial.print("a");
				break;
			case 'B': //high brightness
	      displayContrast(HIGH);
				break;
			case 'b': //low brightness
	      displayContrast(LOW);
				break;
			default:
				CompositeSerial.print("Command not recognized");
		}
  }

  for (uint8_t i = 0; i < 12; i++) {
    keyArray[i].OLED->display();
  };

  for (uint8_t i = 0; i < 12; i++) {
    keyArray[i].Key->read();
  };

}

void displayContrast(boolean contrast) {
  byte contrastSetting = 0x35;
  if (contrast == HIGH) contrastSetting = 0x7F;

  for (uint8_t i = 0; i < 12; i++) {
    keyArray[i].OLED->ssd1306_command(SSD1306_SETCONTRAST);
    keyArray[i].OLED->ssd1306_command(contrastSetting);
  };
}


// See https://github.com/arpruss/USBComposite_stm32f1/blob/master/USBHID.h for actual key presses and value list
// For consumer style value, see https://www.usb.org/sites/default/files/hut1_22.pdf, starting p117
void fVolumeUp(void){
  Consumer.press(HIDConsumer::VOLUME_UP);
  Consumer.release();
}

void fVolumeDown(void){
	Consumer.press(HIDConsumer::VOLUME_DOWN);
  Consumer.release();
}

void fMute(void){
  Consumer.press(HIDConsumer::MUTE);
  Consumer.release();
}

void fLock(void){
	// From https://www.usb.org/sites/default/files/hut1_22.pdf, starting p122
	// AL Terminal Lock/Screensaver
	Consumer.press(0x19E);
  Consumer.release();
}

void fCalc(void){
	Keyboard.press(KEY_LEFT_GUI);
	Keyboard.press('k');
	Keyboard.release('k');
	Keyboard.release(KEY_LEFT_GUI);
}

void fMuteMic(void){
//	Keyboard.press((uint16_t)(0x6F + 0x88)); // Keyboard F20
	Keyboard.press((uint16_t)(0xB0 + 0x88)); // Keyboard F20
	Keyboard.releaseAll();
}

void fCut(void){
	Keyboard.press(KEY_LEFT_CTRL);
	Keyboard.press('x');
	Keyboard.releaseAll();
	// Keyboard.release(KEY_LEFT_CTRL);

	// From https://www.usb.org/sites/default/files/hut1_22.pdf, starting p123
	// AC Cut
	// Consumer.press(0x21C);
	// Consumer.release();
}

void fPaste(void){
  Keyboard.press(KEY_LEFT_CTRL);
  Keyboard.press('v');
	Keyboard.releaseAll();
  // Keyboard.release(KEY_LEFT_CTRL);

	// From https://www.usb.org/sites/default/files/hut1_22.pdf, starting p123
	// AC Paste
	// Consumer.press(0x21D);
	// Consumer.release();
}

void fForward(void){
  Consumer.press(182);
  Consumer.release();
}

void fBackward(void){
  Consumer.press(181);
  Consumer.release();
}

void fPlay(void){
  Consumer.press(HIDConsumer::PLAY_OR_PAUSE);
  Consumer.release();
}

void fTerm(void){
  Keyboard.press(KEY_F12);
  Keyboard.release(KEY_F12);
}

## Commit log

2021-03-24 Keybon12 Eagle Files and BOM
    [Keybon12 REV 1.0.brd, Keybon12 REV 1.0.sch]
2021-03-24 Keybon12 Hardware design files
    [Cover Plate Keybon12.stl, Shell Keybon12.stl]
2021-03-24 Keybon12: update to Arduino code and README
    This new code architecture should make it easier to both add more
    screens if needed, but also to add more functions, including more
    generic ones.
    While usable, this is still a WIP regarding the architecture.
    Also, this work on Keybon12 is backward compatible with the host
    software developped by CoretechR.
2021-03-24 Keybon12: rewrite serial reception with switch statement
2021-04-23 Keybon12: update arduino code

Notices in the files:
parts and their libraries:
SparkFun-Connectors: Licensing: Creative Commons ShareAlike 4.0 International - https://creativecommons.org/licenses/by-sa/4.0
